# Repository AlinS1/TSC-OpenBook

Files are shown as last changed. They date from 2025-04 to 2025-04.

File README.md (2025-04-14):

# OpenBook Project - TSC
### Similea Alin-Andrei 334CA

## Diagrama

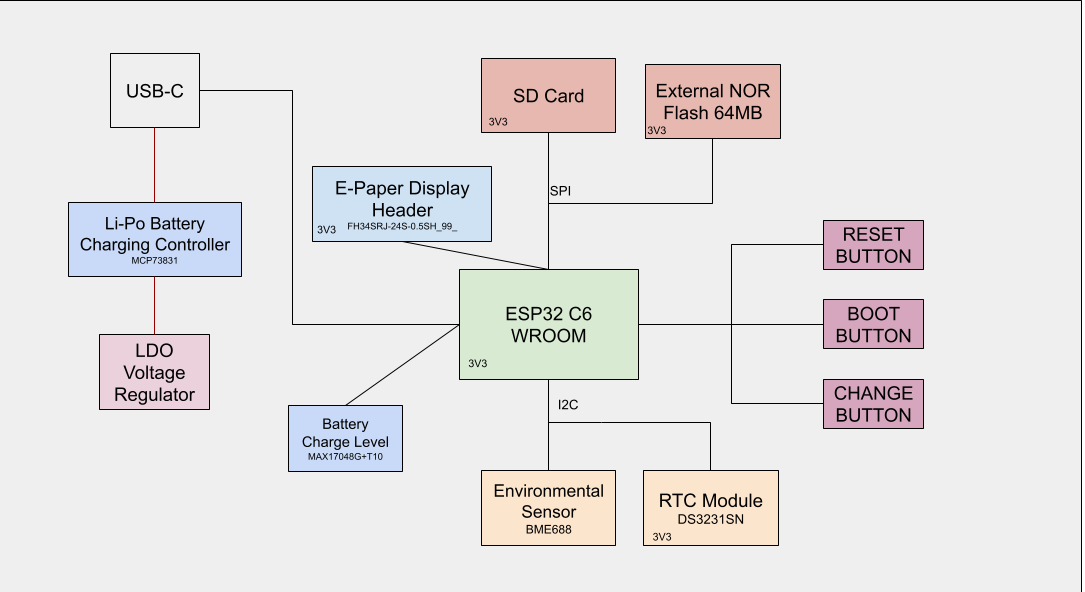
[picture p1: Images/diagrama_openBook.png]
OpenBook Diagram


## Descriere functionalitate hardware
Dispozitivul are in centrul sau un microcontroler ESP32-C6 care interactioneaza cu
un display, un senzor de mediu, un RTC, un SD card si un circuit de gestionare a
alimentarii. Este un dispozitiv alimentat cu baterie, cu conectivitate USB-C.

In ceea ce priveste alimentarea dispozitivului, se foloseste conectorul USB-C
(SAMACSYS_PARTS_USB4110-GF-A) ce dispune de protectie ESD.
Are un controller de incarcare pentru baterii Li-Po(Li-Po Battery Charging
Controller - MCP73831) care se ocupa de incarcarea bateriei.
Mai exista si un stabilizator de tensiune LDO Voltage Regulator (XC6220A331MR-G)
ce asigura o alimentare stabila.
Nivelul de incarcare al bateriei este monitorizat cu ajutorul Battery Charge
Level (MAX17048G+T).

In ceea ce priveste memoria, este inclus un slot pentru card SD
(112A-TAAR-R03_ATTEND). In plus, avem o memorie Flash NOR externa (W25Q512JVIQ)
cu o capacitate de 64MB. Comunicarea cu acestea se face prin SPI (avem MOSI,
MISO, SS_SD si SCK).

Modulul DS3231SN RTC este responsabil pentru mentinerea timpului.
Comunicarea cu controller-ul se face prin I2C (deoarece avem SDA si SCL).
Dispozitivul are integrat si un senzor BME680, destinat analizei aerului,
masurarea presiunii atmosferice, temperaturii si umiditatii. Comunicare cu ESP32
se face tot prin I2C.
Este prezent o componenta Qwiic (QWIIC_CONNECTORJS-1MM) ce ne ajuta sa conectam
usor componente I2C intre ele. 

## Pini ESP32-C6
Modulul DS3231SN RTC foloseste pinii lui ESP32-C6 pentru SDA(19) si SCL(20),
deoarece comunica prin I2C. SDA e folosit pentru transferul de date, iar SCL
este linia de ceas folosita la sincronizare.

Senzorul de mediu BME680 foloseste aceiasi pini ca modulul RTC din aceleasi motive.

Cardul SD foloseste MOSI(7), MISO(27), SS_SD(4) si SCK(6), deoarece comunica prin SPI.

Display-ul E-Paper foloseste pini speciali ca EPD_3V3_C(18), EPD_CS(11), EPD_DC(5),
EPD_RST(21), EPD_BUSY(26).

Butoanele folosesc pinii RESET(3), IO/BOOT(15) si IO/CHANGE(23) pentru a realiza anumite actiuni.

## Rezolvare Erori/Warnings

De-alungul implementarii am avut urmatoarele probleme:
1. Bobina L1 - "Copper Width error" - a trebuit sa modific dimensiunile pad-urilor
din biblioteca data, deoarece nu erau conforme cu DRC-ul.

2. Componenta U4 - "Smd, -Net Class: 1 POWER Top" - Modificam dimensiunea smd-urilor
vizate la 32mil x 16mil.

3. Pentru ca traseele de alimentare sa aiba width (0.3mm) diferit de celelalte
(0.15mm) vom crea o regula custom pentru Copper Width folosind un net class separat
ce contine label-urile destinate traseelor de alimentare.

4. Pentru a ne asigura ca evitam vias-urile la traseele de putere, vom face prima
data rutarea acestora cu ajutorul liniei de comanda.
(auto 3V3 EPD_3V3 EPD_3V3_C VBUS VUSB VBAT VRTC)

## Bill Of Materials

| Schematic name | Value | Component | Footprint Name | Component link | Datasheet link |
|---|---|---|---|---|---|
|	BOOT_BUTTON	|	BUTTON_CUSYOMV1	|	BUTTON_CUSYOMV1	|	MYBUTTON	|	https://industry.panasonic.com/global/en/products/control/switch/light-touch/number/evqpuj02k	|	https://industry.panasonic.com/global/en/downloads?tab=catalog&small_g_cd=203&part_no=EVQPUJ02K	|
|	C1	|	100nF	|	ESP32_WROVER_EAGLE-LTSPICE_CC0402	|	ESP32_WROVER_EAGLE-LTSPICE_C0402	|	https://componentsearchengine.com/part-view/CC0402MRX5R5BB106/YAGEO	|	https://componentsearchengine.com/Datasheets/2/CC0402MRX5R5BB106.pdf	|
|	C1_BAT	|	4.7uF	|	ESP32_WROVER_EAGLE-LTSPICE_CC0402	|	ESP32_WROVER_EAGLE-LTSPICE_C0402	|	https://componentsearchengine.com/part-view/CC0402MRX5R5BB106/YAGEO	|	https://componentsearchengine.com/Datasheets/2/CC0402MRX5R5BB106.pdf	|
|	C1_BAT1	|	4.7uF	|	EAGLE-LTSPICE_CC0402	|	EAGLE-LTSPICE_C0402	|	https://www.snapeda.com/parts/CC0402DRNPO9BN5R1/Yageo/view-part/?ref=dk&t=LTSPICE_CC0402&con_ref=None	|	https://s3.amazonaws.com/snapeda/datasheet/CC0402DRNPO9BN5R1_Yageo.pdf	|
|	C2_BAT1	|	4.7uF	|	EAGLE-LTSPICE_CC0402	|	EAGLE-LTSPICE_C0402	|	https://www.snapeda.com/parts/CC0402DRNPO9BN5R1/Yageo/view-part/?ref=dk&t=LTSPICE_CC0402&con_ref=None	|	https://s3.amazonaws.com/snapeda/datasheet/CC0402DRNPO9BN5R1_Yageo.pdf	|
|	C1_BAT2	|	4.7uF	|	EAGLE-LTSPICE_CC0402	|	EAGLE-LTSPICE_C0402	|	https://www.snapeda.com/parts/CC0402DRNPO9BN5R1/Yageo/view-part/?ref=dk&t=LTSPICE_CC0402&con_ref=None	|	https://s3.amazonaws.com/snapeda/datasheet/CC0402DRNPO9BN5R1_Yageo.pdf	|
|	C2	|	100nF	|	ESP32_WROVER_EAGLE-LTSPICE_CC0402	|	ESP32_WROVER_EAGLE-LTSPICE_C0402	|	https://componentsearchengine.com/part-view/CC0402MRX5R5BB106/YAGEO	|	https://componentsearchengine.com/Datasheets/2/CC0402MRX5R5BB106.pdf	|
|	C2_BAT	|	4.7uF	|	ESP32_WROVER_EAGLE-LTSPICE_CC0402	|	ESP32_WROVER_EAGLE-LTSPICE_C0402	|	https://componentsearchengine.com/part-view/CC0402MRX5R5BB106/YAGEO	|	https://componentsearchengine.com/Datasheets/2/CC0402MRX5R5BB106.pdf	|
|	C3	|	100uF TANT	|	RCL_CPOL-EUCT3528	|	RCL_CT3528	|	https://www.snapeda.com/parts/TAJB475K025RNJ/AVX/view-part/?ref=dk&t=capacitor%203528&con_ref=None	|	https://s3.amazonaws.com/snapeda/datasheet/TAJB475K025RNJ_AVX.pdf	|
|	C4	|	4.7uF/25V	|	ESP32_WROVER_EAGLE-LTSPICE_CC0402	|	ESP32_WROVER_EAGLE-LTSPICE_C0402	|	https://componentsearchengine.com/part-view/CC0402MRX5R5BB106/YAGEO	|	https://componentsearchengine.com/Datasheets/2/CC0402MRX5R5BB106.pdf	|
|	C4_USB	|	100nF	|	ESP32_WROVER_EAGLE-LTSPICE_CC0402	|	ESP32_WROVER_EAGLE-LTSPICE_C0402	|	https://componentsearchengine.com/part-view/CC0402MRX5R5BB106/YAGEO	|	https://componentsearchengine.com/Datasheets/2/CC0402MRX5R5BB106.pdf	|
|	C5	|	1uF	|	ESP32_WROVER_EAGLE-LTSPICE_CC0402	|	ESP32_WROVER_EAGLE-LTSPICE_C0402	|	https://componentsearchengine.com/part-view/CC0402MRX5R5BB106/YAGEO	|	https://componentsearchengine.com/Datasheets/2/CC0402MRX5R5BB106.pdf	|
|	C5_USB	|	4.7uF	|	ESP32_WROVER_EAGLE-LTSPICE_CC0402	|	ESP32_WROVER_EAGLE-LTSPICE_C0402	|	https://componentsearchengine.com/part-view/CC0402MRX5R5BB106/YAGEO	|	https://componentsearchengine.com/Datasheets/2/CC0402MRX5R5BB106.pdf	|
|	C6	|	100nF	|	ESP32_WROVER_EAGLE-LTSPICE_CC0402	|	ESP32_WROVER_EAGLE-LTSPICE_C0402	|	https://componentsearchengine.com/part-view/CC0402MRX5R5BB106/YAGEO	|	https://componentsearchengine.com/Datasheets/2/CC0402MRX5R5BB106.pdf	|
|	C7	|	10uF	|	ESP32_WROVER_EAGLE-LTSPICE_CC0402	|	ESP32_WROVER_EAGLE-LTSPICE_C0402	|	https://componentsearchengine.com/part-view/CC0402MRX5R5BB106/YAGEO	|	https://componentsearchengine.com/Datasheets/2/CC0402MRX5R5BB106.pdf	|
|	C8	|	100nF	|	ESP32_WROVER_EAGLE-LTSPICE_CC0402	|	ESP32_WROVER_EAGLE-LTSPICE_C0402	|	https://componentsearchengine.com/part-view/CC0402MRX5R5BB106/YAGEO	|	https://componentsearchengine.com/Datasheets/2/CC0402MRX5R5BB106.pdf	|
|	C9	|	100nF	|	EAGLE-LTSPICE_CC0402	|	EAGLE-LTSPICE_C0402	|	https://www.snapeda.com/parts/CC0402DRNPO9BN5R1/Yageo/view-part/?ref=dk&t=LTSPICE_CC0402&con_ref=None	|	https://s3.amazonaws.com/snapeda/datasheet/CC0402DRNPO9BN5R1_Yageo.pdf	|
|	C10	|	100nF	|	ESP32_WROVER_EAGLE-LTSPICE_CC0402	|	ESP32_WROVER_EAGLE-LTSPICE_C0402	|	https://componentsearchengine.com/part-view/CC0402MRX5R5BB106/YAGEO	|	https://componentsearchengine.com/Datasheets/2/CC0402MRX5R5BB106.pdf	|
|	C10_SUPERCAP	|	CPH3225A	|	CPH3225A	|	CAPCP3225X100N	|	https://www.snapeda.com/parts/CPH3225A/Seiko+Instruments/view-part/?ref=eda	|	https://www.snapeda.com/parts/CPH3225A/Seiko%20Instruments/datasheet/	|
|	CHANGE_BUTTON	|	BUTTON_CUSYOMV1	|	BUTTON_CUSYOMV1	|	MYBUTTON	|	https://industry.panasonic.com/global/en/products/control/switch/light-touch/number/evqpuj02k	|	https://industry.panasonic.com/global/en/downloads?tab=catalog&small_g_cd=203&part_no=EVQPUJ02K	|
|	CHG_LED	|		|	ADAFRUIT_LEDCHIP-LED0603	|	ADAFRUIT_CHIP-LED0603	|	https://www.snapeda.com/parts/KP-1608SURCK/Kingbright/view-part/?ref=search&t=LED%200603	|	https://www.snapeda.com/parts/KP-1608SURCK/Kingbright/datasheet/	|
|	C_DELAY	|	100nF	|	ESP32_WROVER_EAGLE-LTSPICE_CC0402	|	ESP32_WROVER_EAGLE-LTSPICE_C0402	|	https://componentsearchengine.com/part-view/CC0402MRX5R5BB106/YAGEO	|	https://componentsearchengine.com/Datasheets/2/CC0402MRX5R5BB106.pdf	|
|	D1	|	USBLC6-2SC6Y	|	USBLC6-2SC6Y	|	SOT95P280X145-6N	|	https://www.snapeda.com/parts/USBLC6-2SC6Y/STMicroelectronics/view-part/?ref=snap	|	https://www.snapeda.com/parts/USBLC6-2SC6Y/STMicroelectronics/datasheet/	|
|	D2	|	ESP32_WROVER_AVX---SD0805S020S1R0_AVX_SD0805S020S1R0_0_0AVX_SD0805S020S1R0_0_0	|	ESP32_WROVER_AVX---SD0805S020S1R0_AVX_SD0805S020S1R0_0_0AVX_SD0805S020S1R0_0_0	|	ESP32_WROVER_AVX---SD0805S020S1R0_AVX_SD0805S020S1R0_0	|	https://ro.mouser.com/ProductDetail/KYOCERA-AVX/SD0805S020S1R0?qs=jCA%252BPfw4LHbpkAoSnwrdjw%3D%3D	|	http://datasheets.avx.com/schottky.pdf	|
|	D3	|	MBR0530	|	MBR0530	|	SOD3716X135N	|	https://www.snapeda.com/parts/MBR0530/Onsemi/view-part/?ref=eda	|	https://www.snapeda.com/parts/MBR0530/ON%20Semiconductor/datasheet/	|
|	D4	|	MBR0530	|	MBR0530	|	SOD3716X135N	|	https://www.snapeda.com/parts/MBR0530/Onsemi/view-part/?ref=eda	|	https://www.snapeda.com/parts/MBR0530/ON%20Semiconductor/datasheet/	|
|	D5	|	MBR0530	|	MBR0530	|	SOD3716X135N	|	https://www.snapeda.com/parts/MBR0530/Onsemi/view-part/?ref=eda	|	https://www.snapeda.com/parts/MBR0530/ON%20Semiconductor/datasheet/	|
|	D6	|	PGB1010603MR	|	PGB1010603MR	|	DIOC1608X36N	|	https://www.snapeda.com/parts/PGB1010603MR/Littelfuse/view-part/?ref=eda	|	https://www.snapeda.com/parts/PGB1010603MR/Littelfuse%20Inc./datasheet/	|
|	D7	|	ESP32_WROVER_AVX---SD0805S020S1R0_AVX_SD0805S020S1R0_0_0AVX_SD0805S020S1R0_0_0	|	ESP32_WROVER_AVX---SD0805S020S1R0_AVX_SD0805S020S1R0_0_0AVX_SD0805S020S1R0_0_0	|	ESP32_WROVER_AVX---SD0805S020S1R0_AVX_SD0805S020S1R0_0	|	https://eu.mouser.com/ProductDetail/KYOCERA-AVX/SD0805S020S1R0?qs=jCA%252BPfw4LHbpkAoSnwrdjw%3D%3D	|	http://datasheets.avx.com/schottky.pdf	|
|	D8	|	PGB1010603MR	|	PGB1010603MR	|	DIOC1608X36N	|	https://www.snapeda.com/parts/PGB1010603MR/Littelfuse/view-part/?ref=eda	|	https://www.snapeda.com/parts/PGB1010603MR/Littelfuse%20Inc./datasheet/	|
|	D9	|	PGB1010603MR	|	PGB1010603MR	|	DIOC1608X36N	|	https://www.snapeda.com/parts/PGB1010603MR/Littelfuse/view-part/?ref=eda	|	https://www.snapeda.com/parts/PGB1010603MR/Littelfuse%20Inc./datasheet/	|
|	D10	|	PGB1010603MR	|	PGB1010603MR	|	DIOC1608X36N	|	https://www.snapeda.com/parts/PGB1010603MR/Littelfuse/view-part/?ref=eda	|	https://www.snapeda.com/parts/PGB1010603MR/Littelfuse%20Inc./datasheet/	|
|	D11	|	PGB1010603MR	|	PGB1010603MR	|	DIOC1608X36N	|	https://www.snapeda.com/parts/PGB1010603MR/Littelfuse/view-part/?ref=eda	|	https://www.snapeda.com/parts/PGB1010603MR/Littelfuse%20Inc./datasheet/	|
|	D12	|	PGB1010603MR	|	PGB1010603MR	|	DIOC1608X36N	|	https://www.snapeda.com/parts/PGB1010603MR/Littelfuse/view-part/?ref=eda	|	https://www.snapeda.com/parts/PGB1010603MR/Littelfuse%20Inc./datasheet/	|
|	EPD_C1	|	1uF/50V	|	ESP32_WROVER_EAGLE-LTSPICE_CC0402	|	ESP32_WROVER_EAGLE-LTSPICE_C0402	|	https://componentsearchengine.com/part-view/CC0402MRX5R5BB106/YAGEO	|	https://componentsearchengine.com/Datasheets/2/CC0402MRX5R5BB106.pdf	|
|	EPD_C2	|	1uF/50V	|	ESP32_WROVER_EAGLE-LTSPICE_CC0402	|	ESP32_WROVER_EAGLE-LTSPICE_C0402	|	https://componentsearchengine.com/part-view/CC0402MRX5R5BB106/YAGEO	|	https://componentsearchengine.com/Datasheets/2/CC0402MRX5R5BB106.pdf	|
|	EPD_C5	|	1uF/50V	|	ESP32_WROVER_EAGLE-LTSPICE_CC0402	|	ESP32_WROVER_EAGLE-LTSPICE_C0402	|	https://componentsearchengine.com/part-view/CC0402MRX5R5BB106/YAGEO	|	https://componentsearchengine.com/Datasheets/2/CC0402MRX5R5BB106.pdf	|
|	EPD_C6	|	1uF/50V	|	ESP32_WROVER_EAGLE-LTSPICE_CC0402	|	ESP32_WROVER_EAGLE-LTSPICE_C0402	|	https://componentsearchengine.com/part-view/CC0402MRX5R5BB106/YAGEO	|	https://componentsearchengine.com/Datasheets/2/CC0402MRX5R5BB106.pdf	|
|	EPD_C7	|	1uF/50V	|	ESP32_WROVER_EAGLE-LTSPICE_CC0402	|	ESP32_WROVER_EAGLE-LTSPICE_C0402	|	https://componentsearchengine.com/part-view/CC0402MRX5R5BB106/YAGEO	|	https://componentsearchengine.com/Datasheets/2/CC0402MRX5R5BB106.pdf	|
|	EPD_C8	|	1uF/50V	|	ESP32_WROVER_EAGLE-LTSPICE_CC0402	|	ESP32_WROVER_EAGLE-LTSPICE_C0402	|	https://componentsearchengine.com/part-view/CC0402MRX5R5BB106/YAGEO	|	https://componentsearchengine.com/Datasheets/2/CC0402MRX5R5BB106.pdf	|
|	EPD_C9	|	1uF/50V	|	ESP32_WROVER_EAGLE-LTSPICE_CC0402	|	ESP32_WROVER_EAGLE-LTSPICE_C0402	|	https://componentsearchengine.com/part-view/CC0402MRX5R5BB106/YAGEO	|	https://componentsearchengine.com/Datasheets/2/CC0402MRX5R5BB106.pdf	|
|	EPD_C10	|	1uF/50V	|	ESP32_WROVER_EAGLE-LTSPICE_CC0402	|	ESP32_WROVER_EAGLE-LTSPICE_C0402	|	https://componentsearchengine.com/part-view/CC0402MRX5R5BB106/YAGEO	|	https://componentsearchengine.com/Datasheets/2/CC0402MRX5R5BB106.pdf	|
|	EPD_C11	|	1uF/50V	|	ESP32_WROVER_EAGLE-LTSPICE_CC0402	|	ESP32_WROVER_EAGLE-LTSPICE_C0402	|	https://componentsearchengine.com/part-view/CC0402MRX5R5BB106/YAGEO	|	https://componentsearchengine.com/Datasheets/2/CC0402MRX5R5BB106.pdf	|
|	EPD_C12	|	1uF/50V	|	ESP32_WROVER_EAGLE-LTSPICE_CC0402	|	ESP32_WROVER_EAGLE-LTSPICE_C0402	|	https://componentsearchengine.com/part-view/CC0402MRX5R5BB106/YAGEO	|	https://componentsearchengine.com/Datasheets/2/CC0402MRX5R5BB106.pdf	|
|	IC1	|	BD5229G-TR	|	BD5229G-TR	|	SOT95P280X125-5N	|	https://componentsearchengine.com/part-view/BD5229G-TR/ROHM%20Semiconductor	|	https://datasheet.datasheetarchive.com/originals/distributors/Datasheets_SAMA/f2b9741ef86007909f138d561a359946.pdf	|
|	IC4	|	XC6220A331MR-G	|	XC6220A331MR-G	|	SOT95P280X120-5N	|	https://componentsearchengine.com/part-view/XC6220A331MR-G/Torex	|	https://product.torexsemi.com/system/files/series/xc6220.pdf	|
|	J1	|	FH34SRJ-24S-0.5SH_99_	|	FH34SRJ-24S-0.5SH_99_	|	FH34SRJ24S05SH99	|	https://componentsearchengine.com/part-view/FH34SRJ-24S-0.5SH(99)/Hirose	|	https://www.hirose.com/en/product/document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	|
|	J2	|	SAMACSYS_PARTS_USB4110-GF-A	|	SAMACSYS_PARTS_USB4110-GF-A	|	SAMACSYS_PARTS_USB4110GFA	|	https://componentsearchengine.com/part-view/USB4110-GF-A/GCT%20(GLOBAL%20CONNECTOR%20TECHNOLOGY)	|	https://gct.co/files/drawings/usb4110.pdf	|
|	J3	|	QWIIC_RIGHT_ANGLE	|	QWIIC_CONNECTORJS-1MM	|	JST04_1MM_RA	|	https://grabcad.com/library/sparkfun-qwiic-right-angle-1	|	https://eu.mouser.com/ProductDetail/Adafruit/4208?qs=PzGy0jfpSMtbScLbr0L5dw%3D%3D	|
|	J4	|	112A-TAAR-R03_ATTEND	|	112A-TAAR-R03_ATTEND	|	112ATAARR03ATTEND	|	https://store.comet.srl.ro/Catalogue/Product/43497/	|	https://store.comet.srl.ro/Catalogue/Product/43497/	|
|	L1	|	68uH	|	744043680IND_4828-WE-TPC_WRE	|	IND_4828-WE-TPC_WRE	|	https://ro.mouser.com/ProductDetail/Wurth-Elektronik/744043680?qs=PGXP4M47uW6VkZq%252BkzjrHA%3D%3D	|	https://www.we-online.com/components/products/datasheet/744043680.pdf	|
|	PFMF.050.1	|	ESP32C6_VARISTORCN1812	|	ESP32C6_VARISTORCN1812	|	ESP32C6_VARISTOR_CT/CN1812	|	https://www.mouser.co.uk/ProductDetail/EPCOS-TDK/B72520T0350K062?qs=dEfas%2FXlABIszF52uu7vrg%3D%3D	|	https://www.mouser.co.uk/ProductDetail/EPCOS-TDK/B72520T0350K062?qs=dEfas%2FXlABIszF52uu7vrg%3D%3D	|
|	Q1	|	20V/4.2A/52mO/1.4W	|	ESP32_WROVER_SPARKFUN-DISCRETESEMI_MOSFET_PCH-DMG2305UX-7	|	ESP32_WROVER_SPARKFUN-DISCRETESEMI_SOT23-3	|	https://componentsearchengine.com/part-view/DMG2305UX-7/Diodes%20Incorporated	|	https://www.diodes.com//assets/Datasheets/DMG2305UX.pdf	|
|	Q2	|	20V/4.2A/52mO/1.4W	|	ESP32_WROVER_SPARKFUN-DISCRETESEMI_MOSFET_PCH-DMG2305UX-7	|	ESP32_WROVER_SPARKFUN-DISCRETESEMI_SOT23-3	|	https://componentsearchengine.com/part-view/DMG2305UX-7/Diodes%20Incorporated	|	https://www.diodes.com//assets/Datasheets/DMG2305UX.pdf	|
|	Q3	|	SI1308EDL-T1-GE3	|	D8	|	SOT65P210X110-3N	|	https://componentsearchengine.com/part-view/SI1308EDL-T1-GE3/Vishay	|	https://componentsearchengine.com/Datasheets/1/SI1308EDL-T1-GE3.pdf	|
|	R1	|	10K	|	ESP32_WROVER_EAGLE-LTSPICE_RR0402	|	ESP32_WROVER_EAGLE-LTSPICE_R0402	|	https://componentsearchengine.com/part-view/R0402%201%25%20100%20K%20(RC0402FR-07100KL)/YAGEO	|	https://www.yageo.com/upload/media/product/products/datasheet/rchip/PYu-RC_Group_51_RoHS_L_12.pdf	|
|	R1-PINH	|	10K	|	ESP32_WROVER_EAGLE-LTSPICE_RR0402	|	ESP32_WROVER_EAGLE-LTSPICE_R0402	|	https://componentsearchengine.com/part-view/R0402%201%25%20100%20K%20(RC0402FR-07100KL)/YAGEO	|	https://www.yageo.com/upload/media/product/products/datasheet/rchip/PYu-RC_Group_51_RoHS_L_12.pdf	|
|	R1-PINH1	|	10K	|	ESP32_WROVER_EAGLE-LTSPICE_RR0402	|	ESP32_WROVER_EAGLE-LTSPICE_R0402	|	https://componentsearchengine.com/part-view/R0402%201%25%20100%20K%20(RC0402FR-07100KL)/YAGEO	|	https://www.yageo.com/upload/media/product/products/datasheet/rchip/PYu-RC_Group_51_RoHS_L_12.pdf	|
|	R1_BAT	|	200	|	ESP32_WROVER_EAGLE-LTSPICE_RR0402	|	ESP32_WROVER_EAGLE-LTSPICE_R0402	|	https://componentsearchengine.com/part-view/R0402%201%25%20100%20K%20(RC0402FR-07100KL)/YAGEO	|	https://www.yageo.com/upload/media/product/products/datasheet/rchip/PYu-RC_Group_51_RoHS_L_12.pdf	|
|	R1_PWRUSB	|	100K	|	ESP32_WROVER_EAGLE-LTSPICE_RR0402	|	ESP32_WROVER_EAGLE-LTSPICE_R0402	|	https://componentsearchengine.com/part-view/R0402%201%25%20100%20K%20(RC0402FR-07100KL)/YAGEO	|	https://www.yageo.com/upload/media/product/products/datasheet/rchip/PYu-RC_Group_51_RoHS_L_12.pdf	|
|	R2	|	2.2	|	ESP32_WROVER_EAGLE-LTSPICE_RR0402	|	ESP32_WROVER_EAGLE-LTSPICE_R0402	|	https://componentsearchengine.com/part-view/R0402%201%25%20100%20K%20(RC0402FR-07100KL)/YAGEO	|	https://www.yageo.com/upload/media/product/products/datasheet/rchip/PYu-RC_Group_51_RoHS_L_12.pdf	|
|	R2-PINH	|	10K	|	ESP32_WROVER_EAGLE-LTSPICE_RR0402	|	ESP32_WROVER_EAGLE-LTSPICE_R0402	|	https://componentsearchengine.com/part-view/R0402%201%25%20100%20K%20(RC0402FR-07100KL)/YAGEO	|	https://www.yageo.com/upload/media/product/products/datasheet/rchip/PYu-RC_Group_51_RoHS_L_12.pdf	|
|	R2-PINH1	|	10K	|	ESP32_WROVER_EAGLE-LTSPICE_RR0402	|	ESP32_WROVER_EAGLE-LTSPICE_R0402	|	https://componentsearchengine.com/part-view/R0402%201%25%20100%20K%20(RC0402FR-07100KL)/YAGEO	|	https://www.yageo.com/upload/media/product/products/datasheet/rchip/PYu-RC_Group_51_RoHS_L_12.pdf	|
|	R2-USB	|	5k1	|	ESP32_WROVER_EAGLE-LTSPICE_RR0402	|	ESP32_WROVER_EAGLE-LTSPICE_R0402	|	https://componentsearchengine.com/part-view/R0402%201%25%20100%20K%20(RC0402FR-07100KL)/YAGEO	|	https://www.yageo.com/upload/media/product/products/datasheet/rchip/PYu-RC_Group_51_RoHS_L_12.pdf	|
|	R2-USB1	|	5k1	|	ESP32_WROVER_EAGLE-LTSPICE_RR0402	|	ESP32_WROVER_EAGLE-LTSPICE_R0402	|	https://componentsearchengine.com/part-view/R0402%201%25%20100%20K%20(RC0402FR-07100KL)/YAGEO	|	https://www.yageo.com/upload/media/product/products/datasheet/rchip/PYu-RC_Group_51_RoHS_L_12.pdf	|
|	R2_BAT	|	2K	|	ESP32_WROVER_EAGLE-LTSPICE_RR0402	|	ESP32_WROVER_EAGLE-LTSPICE_R0402	|	https://componentsearchengine.com/part-view/R0402%201%25%20100%20K%20(RC0402FR-07100KL)/YAGEO	|	https://www.yageo.com/upload/media/product/products/datasheet/rchip/PYu-RC_Group_51_RoHS_L_12.pdf	|
|	R3	|	10K	|	ESP32_WROVER_EAGLE-LTSPICE_RR0402	|	ESP32_WROVER_EAGLE-LTSPICE_R0402	|	https://componentsearchengine.com/part-view/R0402%201%25%20100%20K%20(RC0402FR-07100KL)/YAGEO	|	https://www.yageo.com/upload/media/product/products/datasheet/rchip/PYu-RC_Group_51_RoHS_L_12.pdf	|
|	R4	|	10K	|	ESP32_WROVER_EAGLE-LTSPICE_RR0402	|	ESP32_WROVER_EAGLE-LTSPICE_R0402	|	https://componentsearchengine.com/part-view/R0402%201%25%20100%20K%20(RC0402FR-07100KL)/YAGEO	|	https://www.yageo.com/upload/media/product/products/datasheet/rchip/PYu-RC_Group_51_RoHS_L_12.pdf	|
|	R5	|	10K	|	ESP32_WROVER_EAGLE-LTSPICE_RR0402	|	ESP32_WROVER_EAGLE-LTSPICE_R0402	|	https://componentsearchengine.com/part-view/R0402%201%25%20100%20K%20(RC0402FR-07100KL)/YAGEO	|	https://www.yageo.com/upload/media/product/products/datasheet/rchip/PYu-RC_Group_51_RoHS_L_12.pdf	|
|	R6	|	10K	|	ESP32_WROVER_EAGLE-LTSPICE_RR0402	|	ESP32_WROVER_EAGLE-LTSPICE_R0402	|	https://componentsearchengine.com/part-view/R0402%201%25%20100%20K%20(RC0402FR-07100KL)/YAGEO	|	https://www.yageo.com/upload/media/product/products/datasheet/rchip/PYu-RC_Group_51_RoHS_L_12.pdf	|
|	R7	|	10K	|	ESP32_WROVER_EAGLE-LTSPICE_RR0402	|	ESP32_WROVER_EAGLE-LTSPICE_R0402	|	https://componentsearchengine.com/part-view/R0402%201%25%20100%20K%20(RC0402FR-07100KL)/YAGEO	|	https://www.yageo.com/upload/media/product/products/datasheet/rchip/PYu-RC_Group_51_RoHS_L_12.pdf	|
|	R8	|	10K	|	ESP32_WROVER_EAGLE-LTSPICE_RR0402	|	ESP32_WROVER_EAGLE-LTSPICE_R0402	|	https://componentsearchengine.com/part-view/R0402%201%25%20100%20K%20(RC0402FR-07100KL)/YAGEO	|	https://www.yageo.com/upload/media/product/products/datasheet/rchip/PYu-RC_Group_51_RoHS_L_12.pdf	|
|	R9	|	10K	|	ESP32_WROVER_EAGLE-LTSPICE_RR0402	|	ESP32_WROVER_EAGLE-LTSPICE_R0402	|	https://componentsearchengine.com/part-view/R0402%201%25%20100%20K%20(RC0402FR-07100KL)/YAGEO	|	https://www.yageo.com/upload/media/product/products/datasheet/rchip/PYu-RC_Group_51_RoHS_L_12.pdf	|
|	R10	|	10K	|	ESP32_WROVER_EAGLE-LTSPICE_RR0402	|	ESP32_WROVER_EAGLE-LTSPICE_R0402	|	https://componentsearchengine.com/part-view/R0402%201%25%20100%20K%20(RC0402FR-07100KL)/YAGEO	|	https://www.yageo.com/upload/media/product/products/datasheet/rchip/PYu-RC_Group_51_RoHS_L_12.pdf	|
|	RESET_BUTTON	|	BUTTON_CUSYOMV1	|	BUTTON_CUSYOMV1	|	MYBUTTON	|	https://industry.panasonic.com/global/en/products/control/switch/light-touch/number/evqpuj02k	|	https://industry.panasonic.com/global/en/downloads?tab=catalog&small_g_cd=203&part_no=EVQPUJ02K	|
|	R_BOOT	|	10K	|	ESP32_WROVER_EAGLE-LTSPICE_RR0402	|	ESP32_WROVER_EAGLE-LTSPICE_R0402	|	https://componentsearchengine.com/part-view/R0402%201%25%20100%20K%20(RC0402FR-07100KL)/YAGEO	|	https://www.yageo.com/upload/media/product/products/datasheet/rchip/PYu-RC_Group_51_RoHS_L_12.pdf	|
|	R_CAPACITOR	|	15	|	ESP32_WROVER_EAGLE-LTSPICE_RR0402	|	ESP32_WROVER_EAGLE-LTSPICE_R0402	|	https://componentsearchengine.com/part-view/R0402%201%25%20100%20K%20(RC0402FR-07100KL)/YAGEO	|	https://www.yageo.com/upload/media/product/products/datasheet/rchip/PYu-RC_Group_51_RoHS_L_12.pdf	|
|	R_CHANGE	|	10K	|	ESP32_WROVER_EAGLE-LTSPICE_RR0402	|	ESP32_WROVER_EAGLE-LTSPICE_R0402	|	https://componentsearchengine.com/part-view/R0402%201%25%20100%20K%20(RC0402FR-07100KL)/YAGEO	|	https://www.yageo.com/upload/media/product/products/datasheet/rchip/PYu-RC_Group_51_RoHS_L_12.pdf	|
|	R_CL1	|	10K	|	ESP32_WROVER_EAGLE-LTSPICE_RR0402	|	ESP32_WROVER_EAGLE-LTSPICE_R0402	|	https://componentsearchengine.com/part-view/R0402%201%25%20100%20K%20(RC0402FR-07100KL)/YAGEO	|	https://www.yageo.com/upload/media/product/products/datasheet/rchip/PYu-RC_Group_51_RoHS_L_12.pdf	|
|	R_RESET	|	10K	|	ESP32_WROVER_EAGLE-LTSPICE_RR0402	|	ESP32_WROVER_EAGLE-LTSPICE_R0402	|	https://componentsearchengine.com/part-view/R0402%201%25%20100%20K%20(RC0402FR-07100KL)/YAGEO	|	https://www.yageo.com/upload/media/product/products/datasheet/rchip/PYu-RC_Group_51_RoHS_L_12.pdf	|
|	SENSOR2	|	ESP32_WROVER_BME680_BME680	|	ESP32_WROVER_BME680_BME680	|	ESP32_WROVER_BME680_PSON80P300X300X100-8N	|	https://www.snapeda.com/parts/BME680/Bosch/view-part/?welcome=home	|	https://www.snapeda.com/parts/BME680/Bosch%20Sensortec/datasheet/	|
|	SJ1	|	SJ	|	SJ	|	SJ	|	https://grabcad.com/library/solder-jumpers-1	|	https://www.digikey.com/en/htmldatasheets/production/1809569/0/0/1/jumpers	|
|	U1	|	W25Q512JVEIQ	|	W25Q512JVEIQ	|	SON127P600X800X80-9N	|	https://www.snapeda.com/parts/W25Q512JVEIQ/Winbond+Electronics/view-part/?ref=eda	|	https://www.snapeda.com/parts/W25Q512JVEIQ/Winbond%20Electronics/datasheet/	|
|	U2	|	ESP32-C6-WROOM-1-N8	|	ESP32-C6-WROOM-1-N8	|	XCVR_ESP32-C6-WROOM-1-N8	|	https://www.snapeda.com/parts/ESP32-C6-WROOM-1-N8/Espressif+Systems/view-part/?ref=eda	|	https://www.snapeda.com/parts/ESP32-C6-WROOM-1-N8/Espressif%20Systems/datasheet/	|
|	U3	|	DS3231SN#	|	DS3231SN#	|	SOIC127P1032X265-16N	|	https://www.snapeda.com/parts/DS3231SN%23/Analog+Devices/view-part/?ref=eda	|	https://www.snapeda.com/parts/DS3231SN%23/Analog%20Devices/datasheet/	|
|	U4	|	MAX17048G+T10	|	MAX17048G+T10	|	SON50P200X200X80-9N	|	https://www.snapeda.com/parts/MAX17048G+T10/Analog+Devices/view-part/?ref=eda	|	https://www.snapeda.com/parts/MAX17048G+T10/Analog%20Devices/datasheet/	|
|	U5	|	MCP73831	|	ESP32_WROVER_SPARKFUN-IC-POWER_MCP73831	|	ESP32_WROVER_SPARKFUN-IC-POWER_SOT23-5	|	https://ro.mouser.com/ProductDetail/Microchip-Technology/MCP73831T-2ACI-OT?qs=yUQqVecv4qvbBQBGbHx0Mw%3D%3D	|	https://ro.mouser.com/datasheet/2/268/MCP73831_Family_Data_Sheet_DS20001984H-3441711.pdf	|
|	TP1	|	TP	|	TPTP20R	|	TP20R	|		|		|
|	TP2	|	TP	|	TPTP20R	|	TP20R	|		|		|
|	TP3	|	TP	|	TPTP20R	|	TP20R	|		|		|
|	TP4	|	TP	|	TPTP20R	|	TP20R	|		|		|
|	TP5	|	TP	|	TPTP20R	|	TP20R	|		|		|
|	TP6	|	TP	|	TPTP20R	|	TP20R	|		|		|
|	TP7	|	TP	|	TPTP20R	|	TP20R	|		|		|
|	TP8	|	TP	|	TPTP20R	|	TP20R	|		|		|
|	TP9	|	TP	|	TPTP20R	|	TP20R	|		|		|
|	TP10	|	TP	|	TPTP20R	|	TP20R	|		|		|
|	TP11	|	TP	|	TPTP20R	|	TP20R	|		|		|
|	TP12	|	TP	|	TPTP20R	|	TP20R	|		|		|
|	TP13	|	TP	|	TPTP20R	|	TP20R	|		|		|
|	TP14	|	TP	|	TPTP20R	|	TP20R	|		|		|
|	TP15	|	TP	|	TPTP20R	|	TP20R	|		|		|
|	TP16	|	TP	|	TPTP20R	|	TP20R	|		|		|
|	TP17	|	TP	|	TPTP20R	|	TP20R	|		|		|

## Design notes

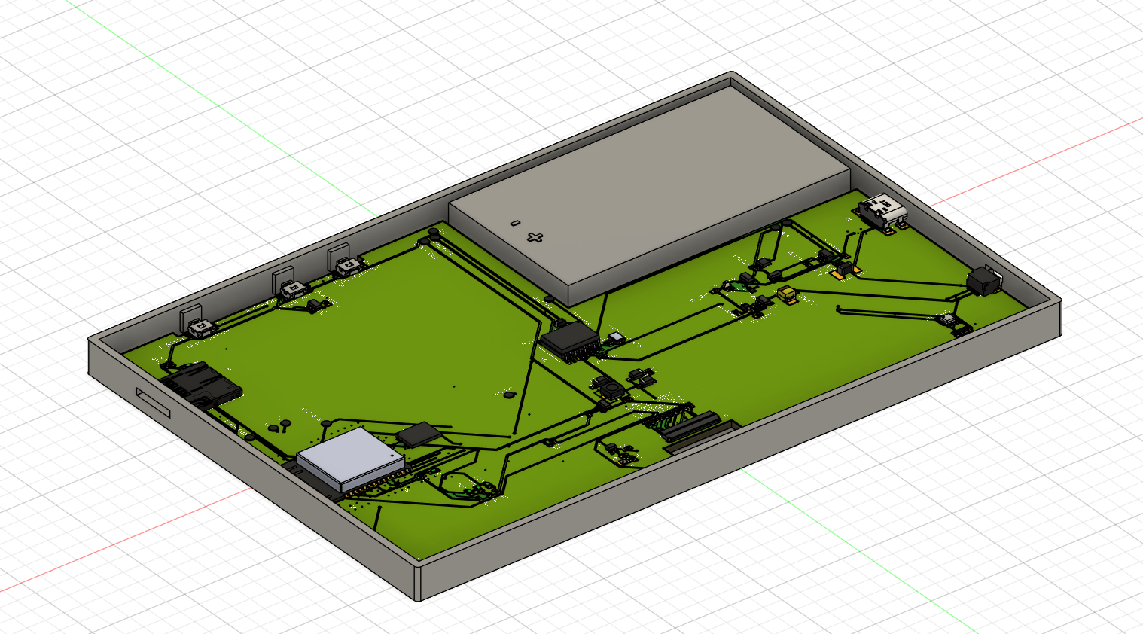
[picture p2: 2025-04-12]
Images/OpenBook_no_lid_2.png

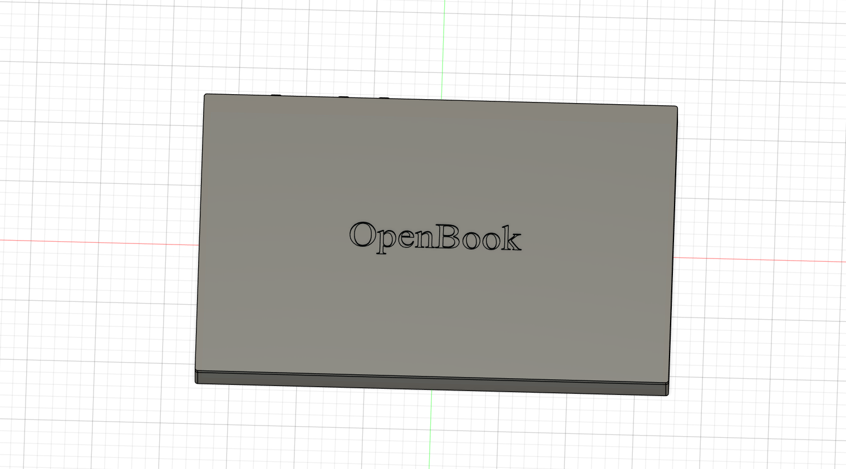
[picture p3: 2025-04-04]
Images/OpenBook_complete.png

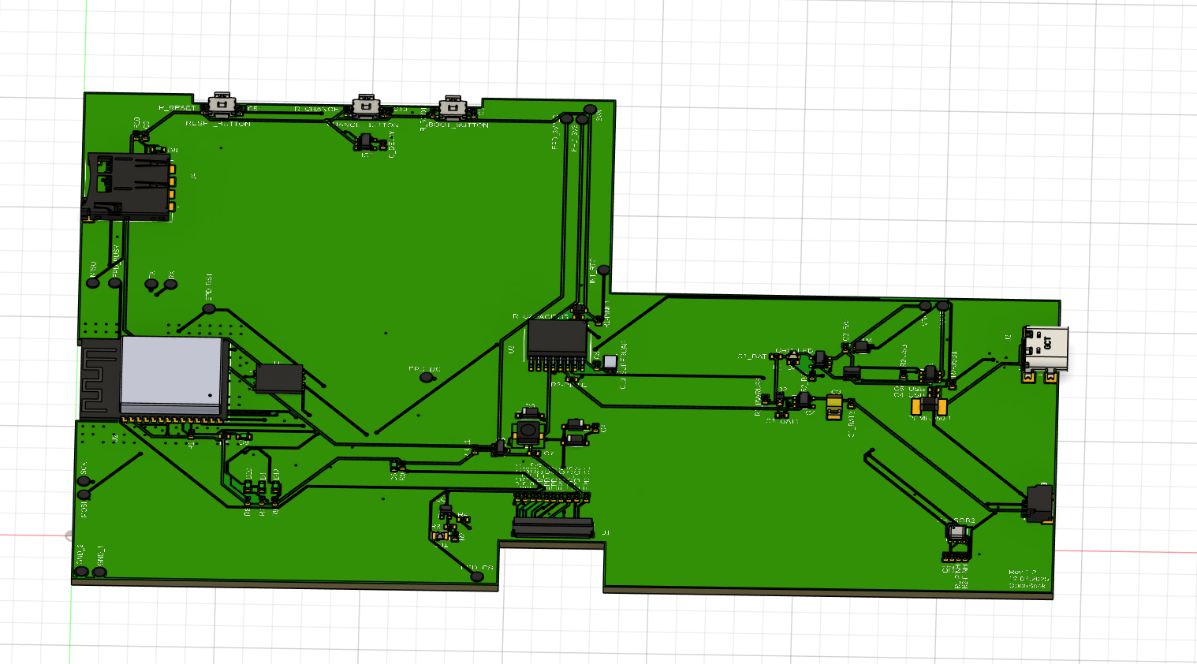
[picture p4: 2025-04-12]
Images/3D_board_top.png

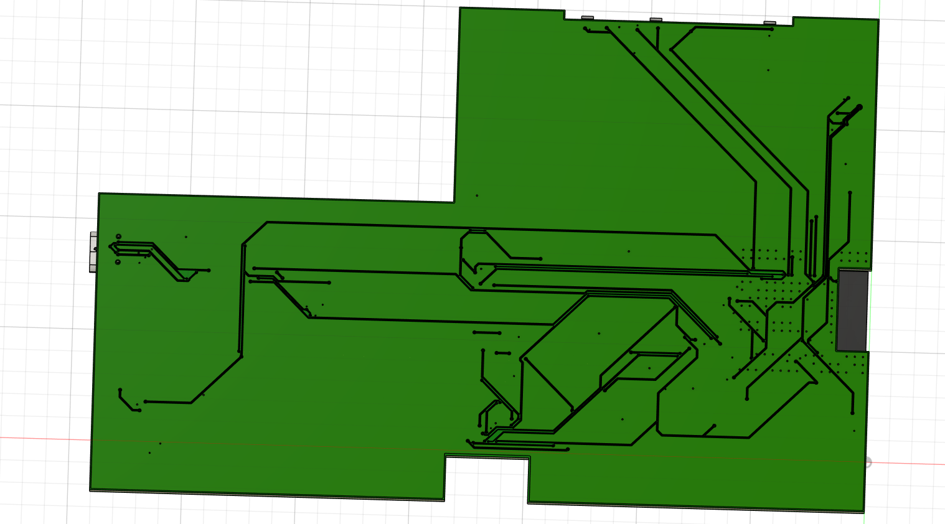
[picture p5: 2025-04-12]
Images/3D_board_bottom.png

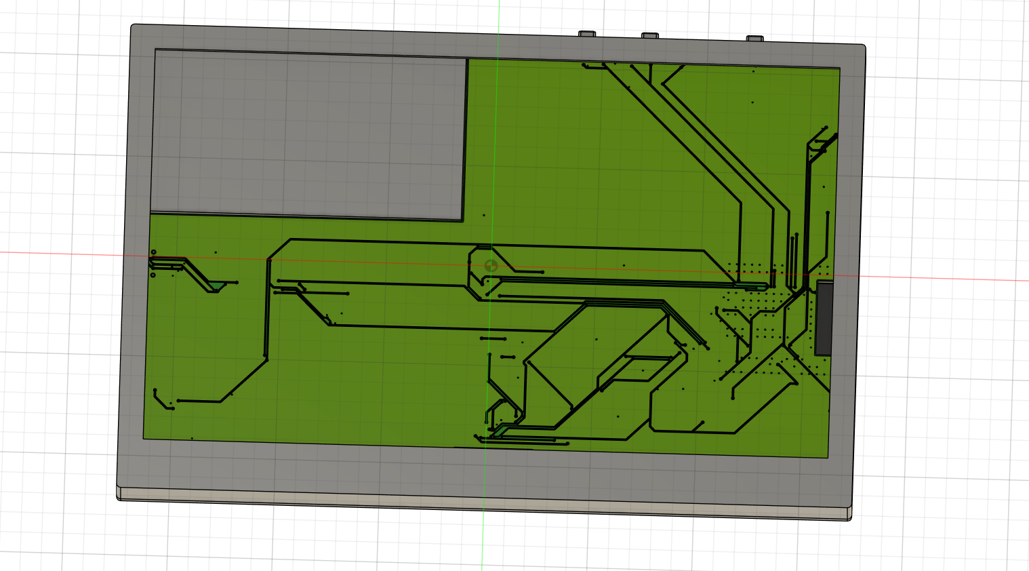
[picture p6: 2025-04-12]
Images/OpenBook_no_screen.png

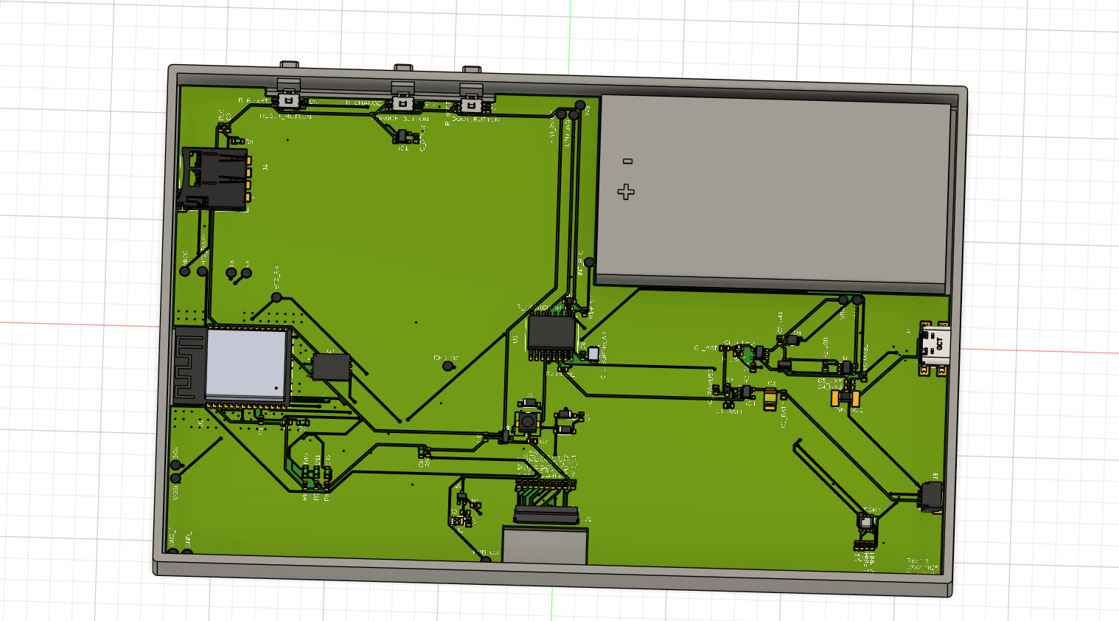
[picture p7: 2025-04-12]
Images/OpenBook_no_lid.png

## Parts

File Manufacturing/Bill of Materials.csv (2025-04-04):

Qty | Value | Device | Package | Parts | Description | VAL
1 |  | ADAFRUIT_LEDCHIP-LED0603 | ADAFRUIT_CHIP-LED0603 | CHG_LED | LED
1 |  |  | SJ | SJ1 | SMD solder JUMPER
1 | 0.1uF/50V | ESP32_WROVER_EAGLE-LTSPICE_CC0402 | ESP32_WROVER_EAGLE-LTSPICE_C0402 | EPD_C5 | CAPACITOR, European symbol
1 | 0.47 | ESP32_WROVER_EAGLE-LTSPICE_RR0402 | ESP32_WROVER_EAGLE-LTSPICE_R0402 | R3 | RESISTOR, European symbol
1 | 100K | ESP32_WROVER_EAGLE-LTSPICE_RR0402 | ESP32_WROVER_EAGLE-LTSPICE_R0402 | R1_PWRUSB | RESISTOR, European symbol
1 | 100Nf | ESP32_WROVER_EAGLE-LTSPICE_CC0402 | ESP32_WROVER_EAGLE-LTSPICE_C0402 | C4_USB | CAPACITOR, European symbol
1 | 100nF | EAGLE-LTSPICE_CC0402 | EAGLE-LTSPICE_C0402 | C9 | CAPACITOR, European symbol
6 | 100nF | ESP32_WROVER_EAGLE-LTSPICE_CC0402 | ESP32_WROVER_EAGLE-LTSPICE_C0402 | C1, C2, C6, C8, C10, C_DELAY | CAPACITOR, European symbol
1 | 100uF TANT | RCL_CPOL-EUCT3528 | RCL_CT3528 | C3 | POLARIZED CAPACITOR, European symbol
16 | 10K | ESP32_WROVER_EAGLE-LTSPICE_RR0402 | ESP32_WROVER_EAGLE-LTSPICE_R0402 | R1, R1-PINH, R1-PINH1, R2-PINH, R2-PINH1, R4, R5, R6, R7, R8, R9, R10, R_BOOT, R_CHANGE, R_CL1, R_RESET | RESISTOR, European symbol
1 | 10uF | ESP32_WROVER_EAGLE-LTSPICE_CC0402 | ESP32_WROVER_EAGLE-LTSPICE_C0402 | C7 | CAPACITOR, European symbol
1 |  |  | 112ATAARR03ATTEND | J4 | Micro SD Card Socket, Push-Push Type, Top Mount, SMT, H=1.83mm, 10u
1 | 15 | ESP32_WROVER_EAGLE-LTSPICE_RR0402 | ESP32_WROVER_EAGLE-LTSPICE_R0402 | R_CAPACITOR | RESISTOR, European symbol
1 | 1uF | ESP32_WROVER_EAGLE-LTSPICE_CC0402 | ESP32_WROVER_EAGLE-LTSPICE_C0402 | C5 | CAPACITOR, European symbol
9 | 1uF/50V | ESP32_WROVER_EAGLE-LTSPICE_CC0402 | ESP32_WROVER_EAGLE-LTSPICE_C0402 | EPD_C1, EPD_C2, EPD_C6, EPD_C7, EPD_C8, EPD_C9, EPD_C10, EPD_C11, EPD_C12 | CAPACITOR, European symbol
1 | 2.2 | ESP32_WROVER_EAGLE-LTSPICE_RR0402 | ESP32_WROVER_EAGLE-LTSPICE_R0402 | R2 | RESISTOR, European symbol
1 | 200 | ESP32_WROVER_EAGLE-LTSPICE_RR0402 | ESP32_WROVER_EAGLE-LTSPICE_R0402 | R1_BAT | RESISTOR, European symbol
2 | 20V/4.2A/52mO/1.4W | ESP32_WROVER_SPARKFUN-DISCRETESEMI_MOSFET_PCH-DMG2305UX-7 | ESP32_WROVER_SPARKFUN-DISCRETESEMI_SOT23-3 | Q1, Q2 | P-channel MOSFETs
1 | 2K | ESP32_WROVER_EAGLE-LTSPICE_RR0402 | ESP32_WROVER_EAGLE-LTSPICE_R0402 | R2_BAT | RESISTOR, European symbol
2 | 4.7uF | EAGLE-LTSPICE_CC0402 | EAGLE-LTSPICE_C0402 | C1_BAT1, C1_BAT2 | CAPACITOR, European symbol
3 | 4.7uF | ESP32_WROVER_EAGLE-LTSPICE_CC0402 | ESP32_WROVER_EAGLE-LTSPICE_C0402 | C1_BAT, C2_BAT, C5_USB | CAPACITOR, European symbol
1 | 4.7uF/25V | ESP32_WROVER_EAGLE-LTSPICE_CC0402 | ESP32_WROVER_EAGLE-LTSPICE_C0402 | C4 | CAPACITOR, European symbol
2 | 5k1 | ESP32_WROVER_EAGLE-LTSPICE_RR0402 | ESP32_WROVER_EAGLE-LTSPICE_R0402 | R2-USB, R2-USB1 | RESISTOR, European symbol
1 | 744043680IND_4828-WE-TPC_WRE | 744043680IND_4828-WE-TPC_WRE | IND_4828-WE-TPC_WRE | L1 |  | 68uH
1 |  |  | SOT95P280X125-5N | IC1 | Voltage Detector with Adjustable Delay Time: CMOS processes are utilized to develop high precision, low current consumption CMOS reset ICs that allow arbitrary setting of the delay time. The extensive lineup includes both Nch Open Drain and CMOS output types in a wide range of detection voltages (from 2.3V to 6.0V, in 0.1V steps), enabling selection of the ideal solution based on customer requirements. In addition, the entire series is of course both lead-free and RoHS-compliant.
3 |  |  | MYBUTTON | BOOT_BUTTON, CHANGE_BUTTON, RESET_BUTTON
1 |  |  | CAPCP3225X100N | C10_SUPERCAP | Cap 0.011F 3.3V 1210 Flat Check availability
1 |  |  | SOIC127P1032X265-16N | U3 | Real Time Clock Serial 16-Pin SOIC W T/R Check availability
1 |  |  | XCVR_ESP32-C6-WROOM-1-N8 | U2 | Check availability
1 | ESP32C6_VARISTORCN1812 | ESP32C6_VARISTORCN1812 | ESP32C6_VARISTOR_CT/CN1812 | PFMF.050.1 | VARISTOR
2 | ESP32_WROVER_AVX---SD0805S020S1R0_AVX_SD0805S020S1R0_0_0AVX_SD0805S020S1R0_0_0 | ESP32_WROVER_AVX---SD0805S020S1R0_AVX_SD0805S020S1R0_0_0AVX_SD0805S020S1R0_0_0 | ESP32_WROVER_AVX---SD0805S020S1R0_AVX_SD0805S020S1R0_0 | D2, D7 | Schottky Barrier Rectifier Diode
1 |  |  | ESP32_WROVER_BME680_PSON80P300X300X100-8N | SENSOR2 | Integrated Environmental Unit
1 |  |  | ESP32_WROVER_SPARKFUN-IC-POWER_SOT23-5 | U5 | MCP73831T Li-Ion, Li-Pol Controller
1 |  |  | FH34SRJ24S05SH99 | J1 | (0.50mm) Surface Mount, Right Angle
1 | MAX17048G+T10 |  | SON50P200X200X80-9N | U4 | Check availability
3 |  |  | SOD3716X135N | D3, D4, D5 | ON SEMICONDUCTOR - MBR0530 - DIODE, SCHOTTKY, 0.5A, 30V, SOD-123
6 |  |  | DIOC1608X36N | D6, D8, D9, D10, D11, D12 | Check availability
1 | QWIIC_RIGHT_ANGLE | QWIIC_CONNECTORJS-1MM | JST04_1MM_RA | J3 | SparkFun I2C Standard Qwiic Connector
1 | SAMACSYS_PARTS_USB4110-GF-ACU3D | SAMACSYS_PARTS_USB4110-GF-ACU3D | SAMACSYS_PARTS_USB4110GFA | J2 | CONN USB 2.0 TYPE-C R/A SMT
1 |  |  | SOT65P210X110-3N | Q3 | MOSFET N-Ch 30V 1.5A TrenchFET SC70 Vishay Si1308EDL-T1-GE3 N-channel MOSFET Transistor, 1.5 A, 30 V, 3-Pin SC-70
17 | TPTP20R | TPTP20R | TP20R | 3V3, EPD_3V3, EPD_3V3_C, EPD_BUSY, EPD_CS, EPD_DC, EPD_RST, GND_1, GND_2, INT_RTC, MISO, MOSI, RX, SCK, TX, VBAT, VBUS | Test pad
1 |  |  | SOT95P280X145-6N | D1 | Low Cap. ESD Protection Auto SOT-23-6 STMicroelectronics USBLC6-2SC6Y, Dual Uni-Directional TVS Diode Array, 6-Pin SOT-23
1 |  |  | SON127P600X800X80-9N | U1 | Check availability
1 |  |  | SOT95P280X120-5N | IC4 | LDO Voltage Regulators

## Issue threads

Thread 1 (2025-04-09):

[PCB] Via Stitching neaplicata

danielgradinaru, 2025-04-09:
Atunci cand am studiat [.brd](https://github.com/AlinS1/TSC-OpenBook/blob/main/Hardware/PCB_start%20v41.brd) nu  am obsevat nicio zona in care ai aplicat Via Stitching.
Adauga Via Stitching in apropierea ESP32.

AlinS1, 2025-04-12:
Via Stitching-ul era aplicat in jurul ESP32, nu stiu din ce cauza nu apare in fisierul .brd. Il voi face din nou.

Closed 2025-04-12.

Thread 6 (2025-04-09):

[PCB] Marcaje de trasabilitate lipsă

danielgradinaru, 2025-04-09:
Layoutul placii [PCB](https://github.com/AlinS1/TSC-OpenBook/blob/main/Hardware/PCB_start%20v41.brd) nu contine marcaje de trasabilitate precum:

- data asamblarii
- versiunea proiectului
- numele proiectului.

Fara aceste marcaje, este dificil să gestionam controlul versiunilor în productie.

Closed 2025-04-12.

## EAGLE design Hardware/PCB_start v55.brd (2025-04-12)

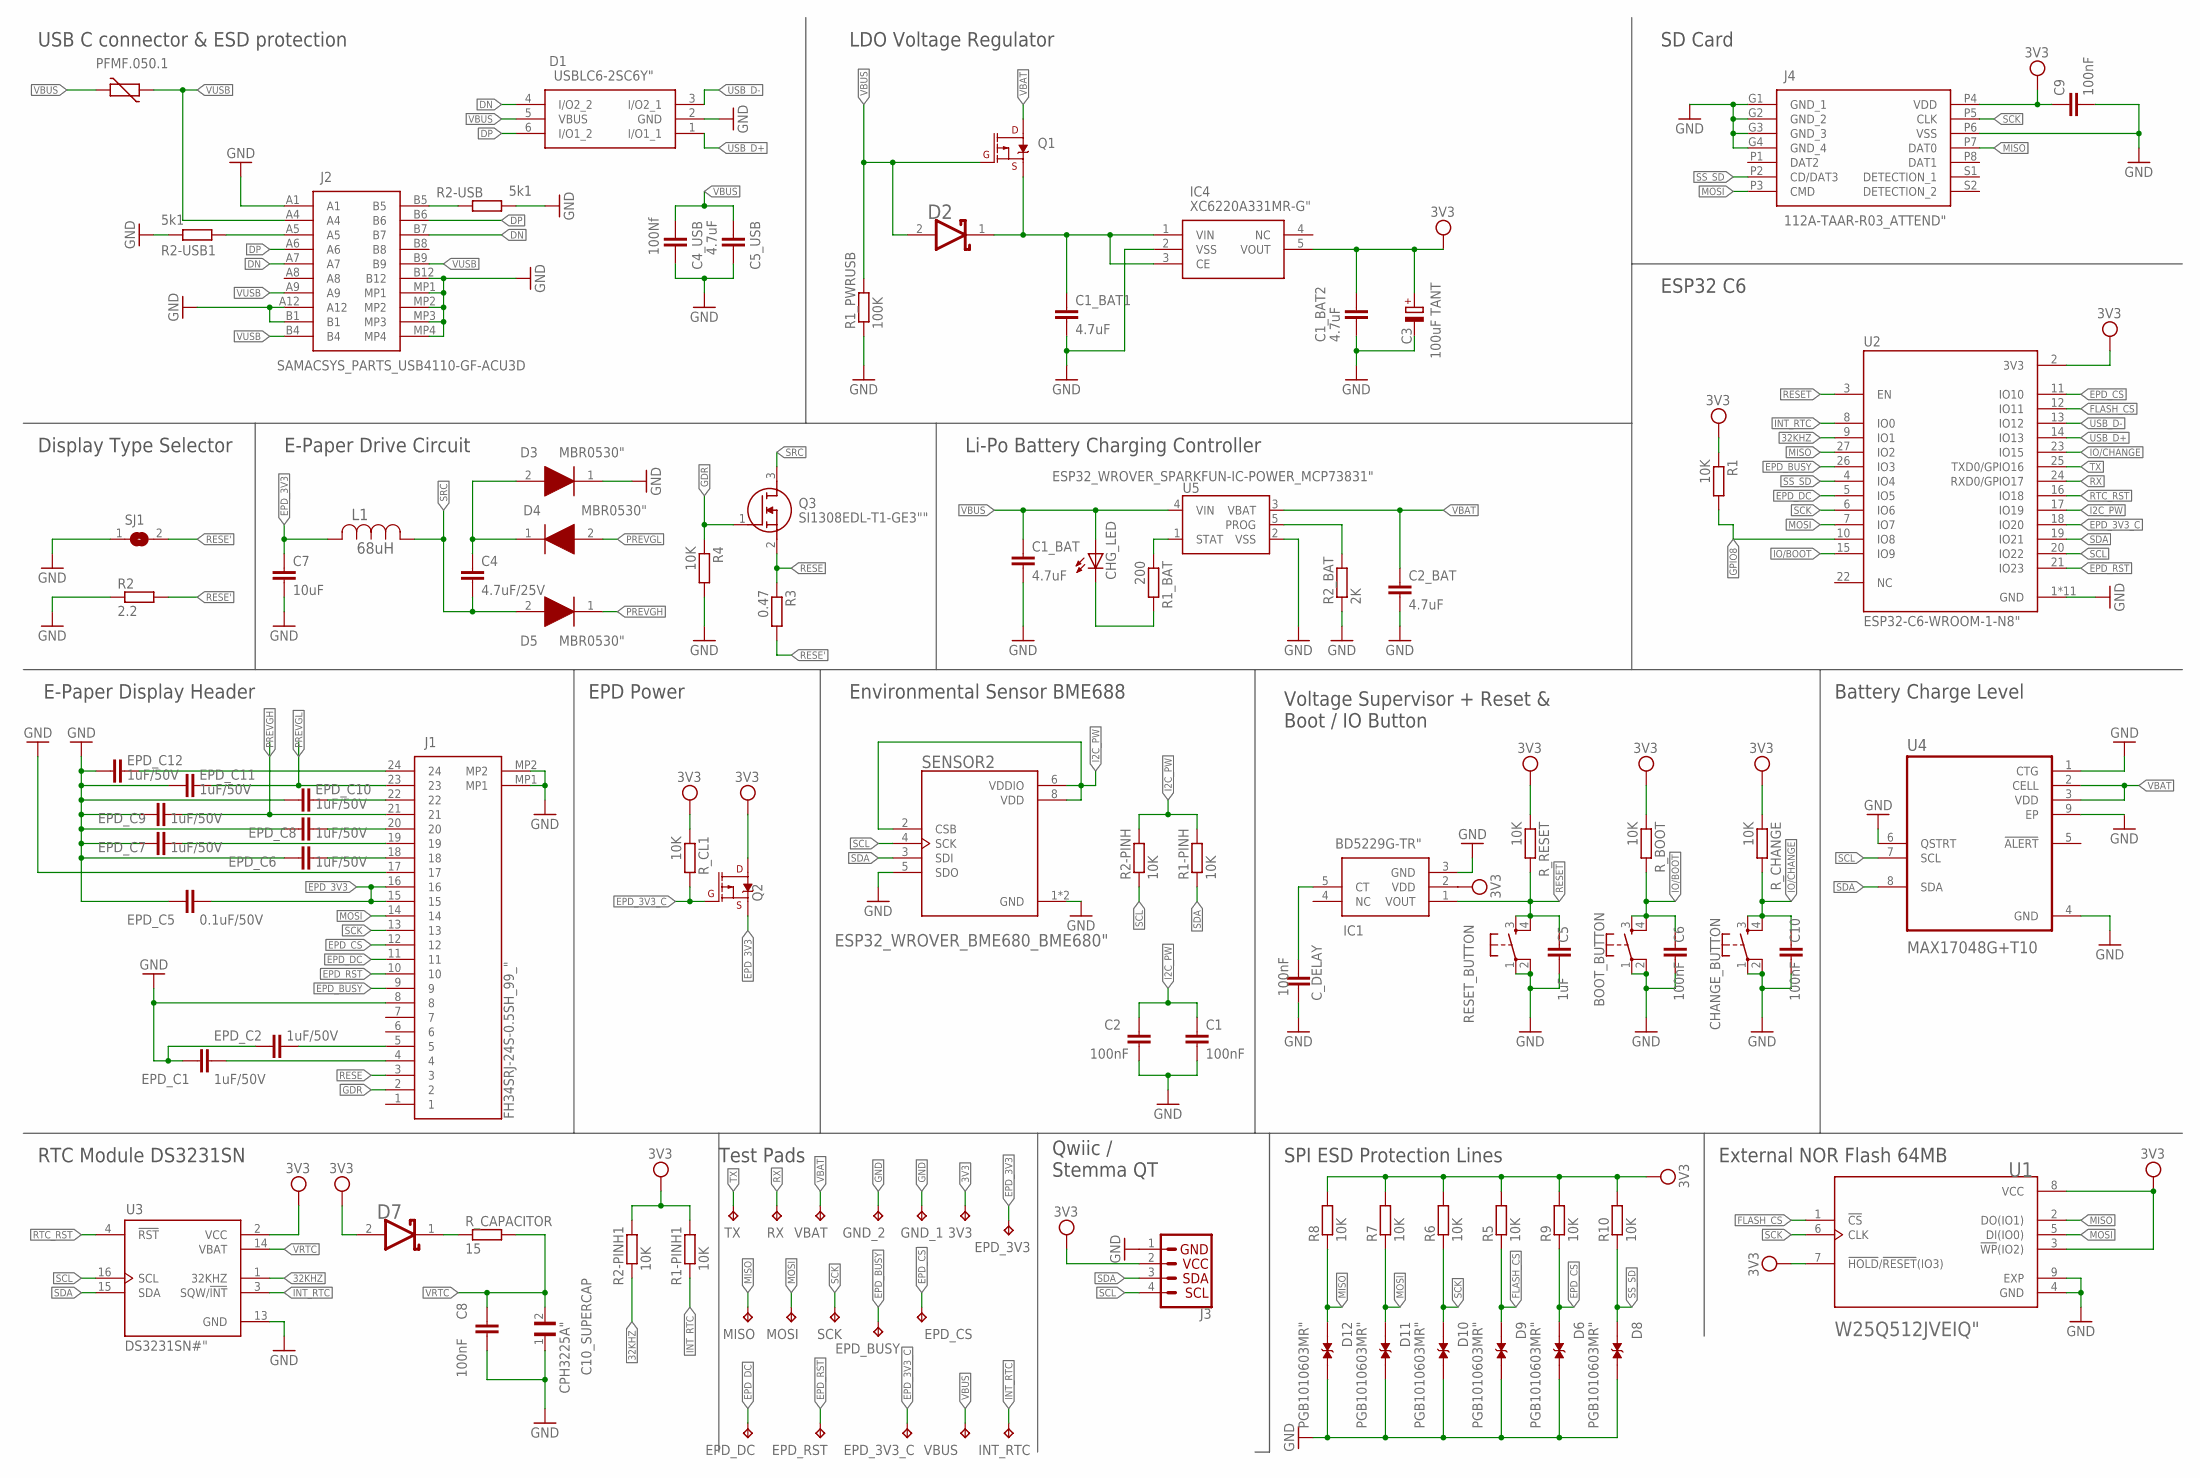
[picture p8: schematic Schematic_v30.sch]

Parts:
3V3: TPTP20R; TP20R
BOOT_BUTTON: BUTTON_CUSYOMV1"; MYBUTTON
C1, C2, C6, C8, C10: 100nF; ESP32_WROVER_EAGLE-LTSPICE_C0402
C1_BAT, C2_BAT, C5_USB: 4.7uF; ESP32_WROVER_EAGLE-LTSPICE_C0402
C1_BAT1, C1_BAT2: 4.7uF; EAGLE-LTSPICE_C0402
C3: 100uF TANT; RCL_CT3528
C4: 4.7uF/25V; ESP32_WROVER_EAGLE-LTSPICE_C0402
C4_USB: 100Nf; ESP32_WROVER_EAGLE-LTSPICE_C0402
C5: 1uF; ESP32_WROVER_EAGLE-LTSPICE_C0402
C7: 10uF; ESP32_WROVER_EAGLE-LTSPICE_C0402
C9: 100nF; EAGLE-LTSPICE_C0402
C10_SUPERCAP: CPH3225A"; CAPCP3225X100N
CHANGE_BUTTON: BUTTON_CUSYOMV1"; MYBUTTON
CHG_LED: ADAFRUIT_LEDCHIP-LED0603; ADAFRUIT_CHIP-LED0603
C_DELAY: 100nF; ESP32_WROVER_EAGLE-LTSPICE_C0402
D1: USBLC6-2SC6Y"; SOT95P280X145-6N
D2, D7: ESP32_WROVER_AVX---SD0805S020S1R0_AVX_SD0805S020S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; ESP32_WROVER_AVX---SD0805S020S1R0_AVX_SD0805S020S1R0_0
D3, D4, D5: MBR0530"; SOD3716X135N
D6, D8, D9, D10, D11, D12: PGB1010603MR"; DIOC1608X36N
EPD_3V3, EPD_3V3_C: TPTP20R; TP20R
EPD_BUSY: TPTP20R; TP20R
EPD_C1, EPD_C2, EPD_C6, EPD_C7, EPD_C8, EPD_C9, EPD_C10, EPD_C11, EPD_C12: 1uF/50V; ESP32_WROVER_EAGLE-LTSPICE_C0402
EPD_C5: 0.1uF/50V; ESP32_WROVER_EAGLE-LTSPICE_C0402
EPD_CS: TPTP20R; TP20R
EPD_DC: TPTP20R; TP20R
EPD_RST: TPTP20R; TP20R
GND_1, GND_2: TPTP20R; TP20R
IC1: BD5229G-TR"; SOT95P280X125-5N
IC4: XC6220A331MR-G"; SOT95P280X120-5N
INT_RTC: TPTP20R; TP20R
J1: FH34SRJ-24S-0.5SH_99_"; FH34SRJ24S05SH99
J2: SAMACSYS_PARTS_USB4110-GF-ACU3D; SAMACSYS_PARTS_USB4110GFA
J3: QWIIC_RIGHT_ANGLE; JST04_1MM_RA
J4: 112A-TAAR-R03_ATTEND"; 112ATAARR03ATTEND
L1: 744043680IND_4828-WE-TPC_WRE; IND_4828-WE-TPC_WRE
MISO: TPTP20R; TP20R
MOSI: TPTP20R; TP20R
PFMF.050.1: ESP32C6_VARISTORCN1812; ESP32C6_VARISTOR_CT/CN1812
Q1, Q2: 20V/4.2A/52mΩ/1.4W; ESP32_WROVER_SPARKFUN-DISCRETESEMI_SOT23-3
Q3: SI1308EDL-T1-GE3""; SOT65P210X110-3N
R1, R1-PINH, R1-PINH1, R2-PINH, R2-PINH1, R4, R5, R6, R7, R8, R9, R10: 10K; ESP32_WROVER_EAGLE-LTSPICE_R0402
R1_BAT: 200; ESP32_WROVER_EAGLE-LTSPICE_R0402
R1_PWRUSB: 100K; ESP32_WROVER_EAGLE-LTSPICE_R0402
R2: 2.2; ESP32_WROVER_EAGLE-LTSPICE_R0402
R2-USB, R2-USB1: 5k1; ESP32_WROVER_EAGLE-LTSPICE_R0402
R2_BAT: 2K; ESP32_WROVER_EAGLE-LTSPICE_R0402
R3: 0.47; ESP32_WROVER_EAGLE-LTSPICE_R0402
RESET_BUTTON: BUTTON_CUSYOMV1"; MYBUTTON
RX: TPTP20R; TP20R
R_BOOT: 10K; ESP32_WROVER_EAGLE-LTSPICE_R0402
R_CAPACITOR: 15; ESP32_WROVER_EAGLE-LTSPICE_R0402
R_CHANGE: 10K; ESP32_WROVER_EAGLE-LTSPICE_R0402
R_CL1: 10K; ESP32_WROVER_EAGLE-LTSPICE_R0402
R_RESET: 10K; ESP32_WROVER_EAGLE-LTSPICE_R0402
SCK: TPTP20R; TP20R
SENSOR2: ESP32_WROVER_BME680_BME680"; ESP32_WROVER_BME680_PSON80P300X300X100-8N
SJ1: SJ""; SJ
TX: TPTP20R; TP20R
U1: W25Q512JVEIQ"; SON127P600X800X80-9N
U2: ESP32-C6-WROOM-1-N8"; XCVR_ESP32-C6-WROOM-1-N8
U3: DS3231SN#"; SOIC127P1032X265-16N
U4: MAX17048G+T10; SON50P200X200X80-9N
U5: ESP32_WROVER_SPARKFUN-IC-POWER_MCP73831"; ESP32_WROVER_SPARKFUN-IC-POWER_SOT23-5
VBAT: TPTP20R; TP20R
VBUS: TPTP20R; TP20R

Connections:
3V3: 3V3.TP, C1_BAT2.1, C3.+, C9.1, D7.2 (ANODE), IC1.2 (VDD), IC4.5 (VOUT), J3.2, J4.P4 (VDD), Q2.3 (D), R1.1, R1-PINH1.2, R2-PINH1.2, R5.2, R6.2, R7.2, R8.2, R9.2, R10.2, R_BOOT.1, R_CHANGE.1, R_CL1.1, R_RESET.1, U1.3 (!WP!(IO2)), U1.7 (!HOLD!/!RESET!(IO3)), U1.8 (VCC), U2.2 (3V3), U3.2 (VCC)
32KHZ: R2-PINH1.1, U2.9 (IO1), U3.1 (32KHZ)
DN: D1.4 (I/O2_2), J2.A7, J2.B7
DP: D1.6 (I/O1_2), J2.A6, J2.B6
EPD_3V3: C7.1, EPD_3V3.TP, EPD_C5.1, J1.15, J1.16, L1.2, Q2.2 (S)
EPD_3V3_C: EPD_3V3_C.TP, Q2.1 (G), R_CL1.2, U2.18 (IO20)
EPD_BUSY: EPD_BUSY.TP, J1.9, U2.26 (IO3)
EPD_CS: D6.1, EPD_CS.TP, J1.12, R9.1, U2.11 (IO10)
EPD_DC: EPD_DC.TP, J1.11, U2.5 (IO5)
EPD_RST: EPD_RST.TP, J1.10, U2.21 (IO23)
FLASH_CS: D9.1, R5.1, U1.1 (!CS), U2.12 (IO11)
GDR: J1.2, Q3.1 (G), R4.1
GND: BOOT_BUTTON.1, BOOT_BUTTON.2, C1.2, C1_BAT.2, C1_BAT1.2, C1_BAT2.2, C2.2, C2_BAT.2, C3.-, C4_USB.2, C5.2, C5_USB.2, C6.2, C7.2, C8.2, C9.2, C10.2, C10_SUPERCAP.1, CHANGE_BUTTON.1, CHANGE_BUTTON.2, C_DELAY.2, D1.2 (GND), D3.1 (K), D6.2, D8.2, D9.2, D10.2, D11.2, D12.2, EPD_C1.2, EPD_C2.2, EPD_C5.2, EPD_C6.2, EPD_C7.2, EPD_C8.2, EPD_C9.2, EPD_C10.2, EPD_C11.2, EPD_C12.2, GND_1.TP, GND_2.TP, IC1.3 (GND), IC4.2 (VSS), J1.8, J1.17, J1.MP1, J1.MP2, J2.A1, J2.A12, J2.B1, J2.B12, J2.MP1, J2.MP2, J2.MP3, J2.MP4, J3.1, J4.G1 (GND_1), J4.G2 (GND_2), J4.G3 (GND_3), J4.G4 (GND_4), J4.P6 (VSS), R1_PWRUSB.1, R2.1, R2-USB.2, R2-USB1.1, R2_BAT.1, R4.2, RESET_BUTTON.1, RESET_BUTTON.2, SENSOR2.1 (GND), SENSOR2.5 (SDO), SENSOR2.7 (GND), SJ1.1, U1.4 (GND), U1.9 (EXP), U2.1 (GND), U2.28 (GND), U2.29_1 (GND), U2.29_2 (GND), U2.29_3 (GND), U2.29_4 (GND), U2.29_5 (GND), U2.29_6 (GND), U2.29_7 (GND), U2.29_8 (GND), U2.29_9 (GND), U3.13 (GND), U4.1 (CTG), U4.4 (GND), U4.6 (QSTRT), U4.9 (EP), U5.2 (VSS)
GPIO8: R1.2, U2.10 (IO8)
I2C_PW: C1.1, C2.1, R1-PINH.2, R2-PINH.2, SENSOR2.2 (CSB), SENSOR2.6 (VDDIO), SENSOR2.8 (VDD), U2.17 (IO19)
INT_RTC: INT_RTC.TP, R1-PINH1.1, U2.8 (IO0), U3.3 (SQW/!INT)
IO/BOOT: BOOT_BUTTON.3, BOOT_BUTTON.4, C6.1, R_BOOT.2, U2.15 (IO9)
IO/CHANGE: C10.1, CHANGE_BUTTON.3, CHANGE_BUTTON.4, R_CHANGE.2, U2.23 (IO15)
MISO: D12.1, J4.P7 (DAT0), MISO.TP, R8.1, U1.2 (DO(IO1)), U2.27 (IO2)
MOSI: D11.1, J1.14, J4.P3 (CMD), MOSI.TP, R7.1, U1.5 (DI(IO0)), U2.7 (IO7)
unnamed: C1_BAT1.1, D2.1 (CATHODE), IC4.1 (VIN), IC4.3 (CE), Q1.2 (S)
unnamed: C_DELAY.1, IC1.5 (CT)
unnamed: J2.B5, R2-USB.1
unnamed: J2.A5, R2-USB1.2
unnamed: R1_BAT.1, U5.1 (STAT)
unnamed: CHG_LED.C, R1_BAT.2
unnamed: C4.1, D3.2 (A), D4.1 (K)
unnamed: R2_BAT.2, U5.5 (PROG)
unnamed: EPD_C1.1, J1.4
unnamed: EPD_C2.1, J1.5
unnamed: D7.1 (CATHODE), R_CAPACITOR.1
unnamed: EPD_C6.1, J1.18
unnamed: EPD_C7.1, J1.19
unnamed: EPD_C8.1, J1.20
unnamed: EPD_C10.1, J1.22
unnamed: EPD_C12.1, J1.24
PREVGH: D5.1 (K), EPD_C9.1, J1.21
PREVGL: D4.2 (A), EPD_C11.1, J1.23
RESE: J1.3, Q3.2 (S), R3.1
RESE': R2.2, R3.2, SJ1.2
RESET: C5.1, IC1.1 (VOUT), RESET_BUTTON.3, RESET_BUTTON.4, R_RESET.2, U2.3 (EN)
RTC_RST: U2.16 (IO18), U3.4 (!RST)
RX: RX.TP, U2.24 (RXD0/GPIO17)
SCK: D10.1, J1.13, J4.P5 (CLK), R6.1, SCK.TP, U1.6 (CLK), U2.6 (IO6)
SCL: J3.4, R2-PINH.1, SENSOR2.4 (SCK), U2.20 (IO22), U3.16 (SCL), U4.7 (SCL)
SDA: J3.3, R1-PINH.1, SENSOR2.3 (SDI), U2.19 (IO21), U3.15 (SDA), U4.8 (SDA)
SRC: C4.2, D5.2 (A), L1.1, Q3.3 (D)
SS_SD: D8.1, J4.P2 (CD/DAT3), R10.1, U2.4 (IO4)
TX: TX.TP, U2.25 (TXD0/GPIO16)
USB_D+: D1.1 (I/O1_1), U2.14 (IO13)
USB_D-: D1.3 (I/O2_1), U2.13 (IO12)
VBAT: C2_BAT.1, Q1.3 (D), U4.2 (CELL), U4.3 (VDD), U5.3 (VBAT), VBAT.TP
VBUS: C1_BAT.1, C4_USB.1, C5_USB.1, CHG_LED.A, D1.5 (VBUS), D2.2 (ANODE), PFMF.050.1.2, Q1.1 (G), R1_PWRUSB.2, U5.4 (VIN), VBUS.TP
VRTC: C8.1, C10_SUPERCAP.2, R_CAPACITOR.2, U3.14 (VBAT)
VUSB: J2.A4, J2.A9, J2.B4, J2.B9, PFMF.050.1.1

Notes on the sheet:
USB C connector & ESD protection
LDO Voltage Regulator
SD Card
ESP32 C6
Li-Po Battery Charging Controller
E-Paper Drive Circuit
Display Type Selector
E-Paper Display Header
EPD Power
Environmental Sensor BME688
Voltage Supervisor + Reset & Boot / IO Button
Battery Charge Level
RTC Module DS3231SN
Test Pads
Qwiic / Stemma QT
SPI ESD Protection Lines
External NOR Flash 64MB

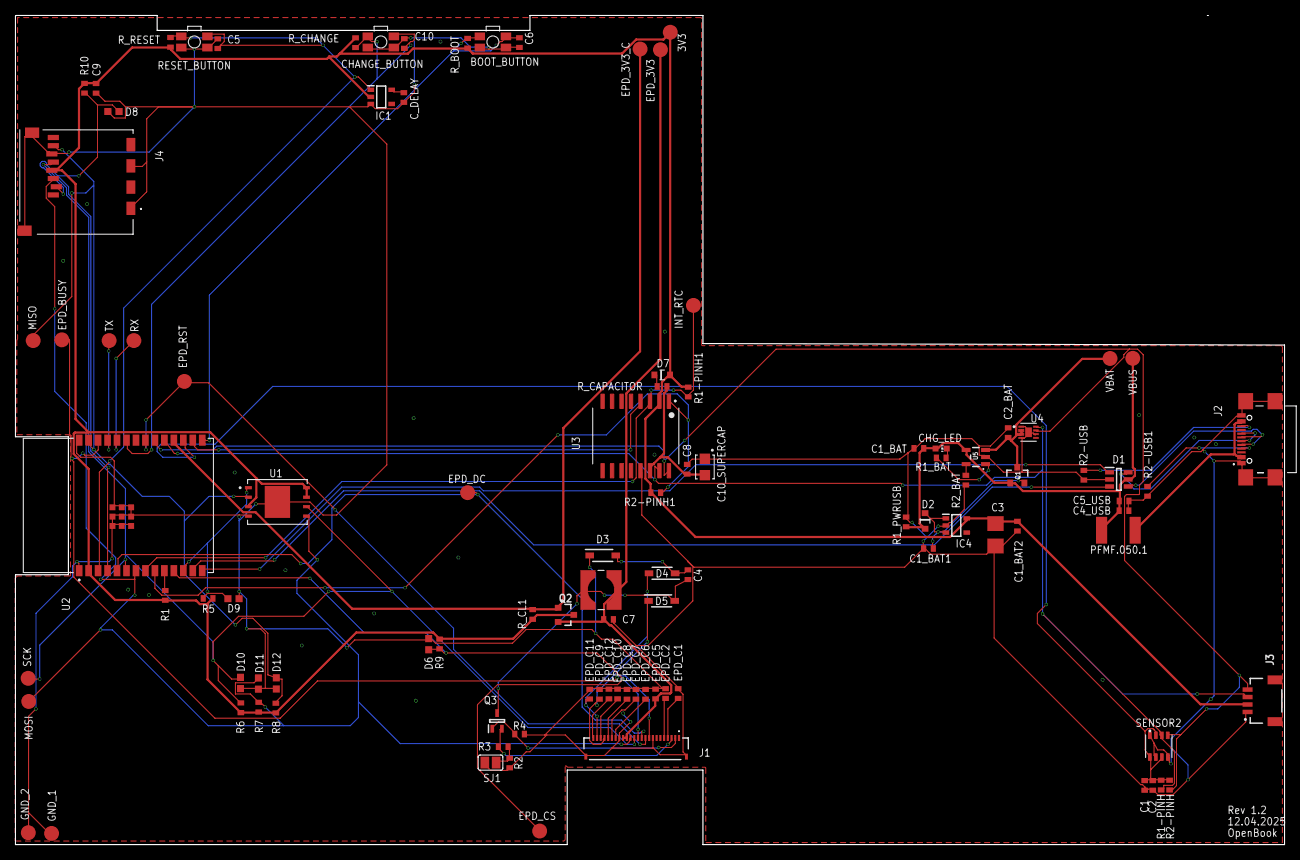
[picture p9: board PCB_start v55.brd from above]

Board: 2 copper layers, 170.2 x 111.2 mm, 103 parts (0 on the bottom side), 55 nets.

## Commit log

2025-04-04 proj - to do README
    [Bill of Materials.csv, PCB_start v41.brd, Pick and Place.csv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]
2025-04-12 Solved issues
    [PCB_start v41.brd, PCB_start v55.brd, Schematic_v24.sch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]
